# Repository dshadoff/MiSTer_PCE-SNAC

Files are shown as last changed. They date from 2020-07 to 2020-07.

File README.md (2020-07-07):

# MiSTer_PCE-SNAC converter board

This is a board designed to work with the MiSTer FPGA system, and is originally based on
the SNAC designs from blue212 at https://github.com/blue212/SNAC

The PC Engine controller system has higher-speed requirements than most other systems, and
as a result, the regular open-collector SNAC boards don't really work for most situations
(ie. auto-fire, 6-button controller, turbotap, PCE mouse, Memory Base 128, etc.).  This is
because the rise time on the pulses is not fast enough among other things.  This board
was designed to address these issues.

While designing it, I also felt that I wanted as small a board as possible, so I decided
to integrate the regular "surfboard" SNAC and the adapter, integrating them into a single
device.  I also shrunk all the components as much as possible, and chose easily-obtainable
parts so that I could get them assembled by JLCPCB's SMT assembly service at a very good
price.  (However they don't mount connectors.)

I designed the board using the free version of EAGLE (2-layer, less than 100mm on both
X- and Y-axes).  The gerbers are included in this repository, including the files required
by JLCPCB's SMT assembly forms, in case you want to get your own set made.

The board measures 37mm x 22mm (plus USB plug).  Here is a picture:

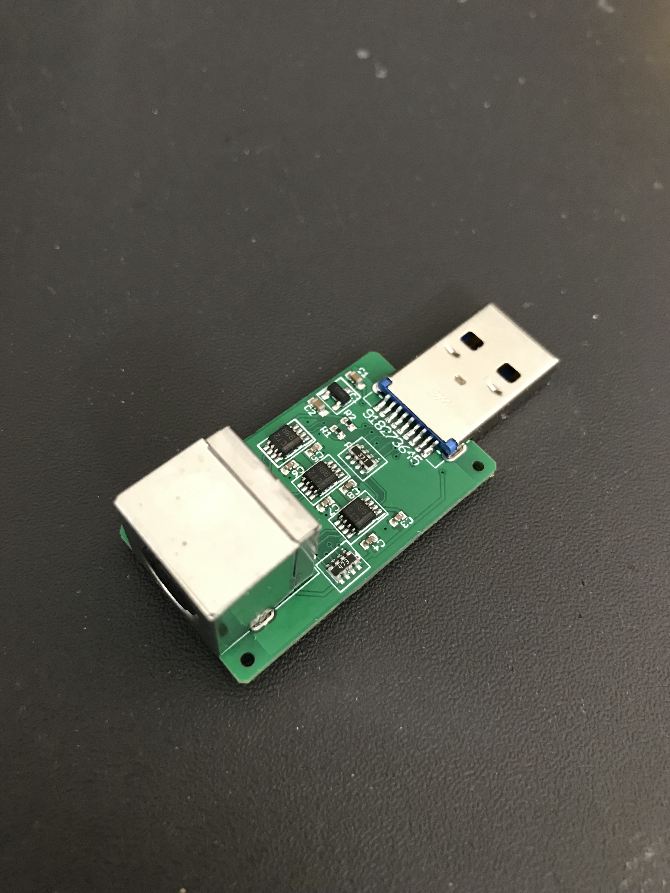
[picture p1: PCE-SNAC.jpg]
PC Board is 37mm x 22mm


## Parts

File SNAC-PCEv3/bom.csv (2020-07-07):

Qty | Designator | Footprint | Comment | LCSC Part # (optional) | Description (optional)
6 | C3, C4, C5, C6, C7, C8 | C0402 | 100nF ±10% 16V X7R 0402 | C1525 | Samsung CL05B104KO5NNNC
2 | C1, C2 | C0603 | 1uF ±10% 50V X5R 0603 | C15849 | Samsung CL10A105KB8NNNC
2 | R1, R2 | R0402 | 3.9K ±1% 1/16W 0402 | C51721 | UNI-ROYAL 0402WGF3901TCE
1 | K2 | through-hole | do not mount |  | USB 3.0 male plug - DO NOT MOUNT
1 | IC1 | SOT-23-3 | MCP1700T-3302E/TT | C39051 | MCP1700T-3302E_TT LDO voltage regulator 250mA Isupply 1uA
1 | J1 | through-hole | do not mount |  | mini-DIN 8-pin socket - DO NOT MOUNT
3 | IC2, IC3, IC4 | SM8 | SN74LVC2T45DCTR | C22672 | Translation - Voltage Levels DUAL-BIT DUAL SUPPLY TRANSCEIVER
1 | RN2 | 0603_x4 | 330 ±5% x4 1/16W network | C12018 | UNI-ROYAL 4D03WGJ0331T5E
1 | RN1 | 0603_x4 | 47K ±5% x4 1/16W network | C12027 | UNI-ROYAL 4D03WGJ0473T5E

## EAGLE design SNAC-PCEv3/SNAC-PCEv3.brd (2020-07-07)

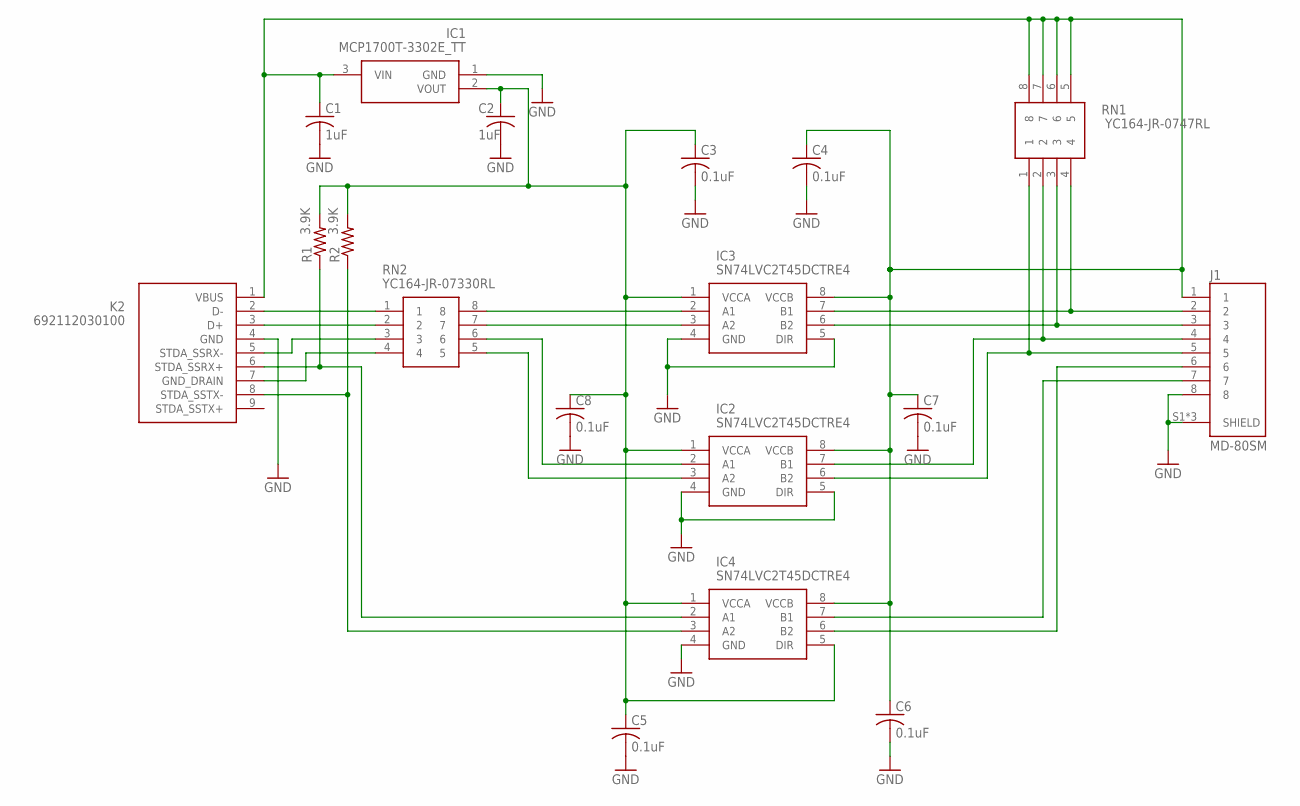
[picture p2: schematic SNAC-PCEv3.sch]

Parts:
C1, C2: 1uF; C0603
C3, C4, C5, C6, C7, C8: 0.1uF; C0402
IC1: MCP1700T-3302E_TT; SOT95P237X112-3N
IC2, IC3, IC4: SN74LVC2T45DCTRE4; SOP65P400X130-8N
J1: MD-80SM; CUI_MD-80SM
K2: 692112030100; MPN TXS0108EPWR
R1, R2: 3.9K; R0402
RN1: YC164-JR-0747RL; YC164JR07220RL
RN2: YC164-JR-07330RL; YC164JR07220RL

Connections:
3V3: C2.1, C3.1, C5.1, C8.1, IC1.2 (VOUT), IC2.1 (VCCA), IC3.1 (VCCA), IC4.1 (VCCA), IC4.5 (DIR), R1.2, R2.2
5V: C1.1, C4.1, C6.1, C7.1, IC1.3 (VIN), IC2.8 (VCCB), IC3.8 (VCCB), IC4.8 (VCCB), J1.1, K2.1 (VBUS), RN1.5, RN1.6, RN1.7, RN1.8
GND: C1.2, C2.2, C3.2, C4.2, C5.2, C6.2, C7.2, C8.2, IC1.1 (GND), IC2.4 (GND), IC2.5 (DIR), IC3.4 (GND), IC3.5 (DIR), IC4.4 (GND), J1.8, J1.S1 (SHIELD), J1.S2 (SHIELD), J1.S3 (SHIELD), K2.4 (GND)
unnamed: K2.2 (D-), RN2.1
unnamed: IC3.7 (B1), J1.2, RN1.4
unnamed: IC3.3 (A2), RN2.7
unnamed: IC2.7 (B1), J1.4, RN1.2
unnamed: IC3.2 (A1), RN2.8
unnamed: K2.3 (D+), RN2.2
unnamed: K2.5 (STDA_SSRX-), RN2.3
unnamed: IC4.7 (B1), J1.7
unnamed: IC3.6 (B2), J1.3, RN1.3
unnamed: IC2.6 (B2), J1.5, RN1.1
unnamed: IC4.6 (B2), J1.6
unnamed: IC2.2 (A1), RN2.6
unnamed: K2.7 (GND_DRAIN), RN2.4
unnamed: IC2.3 (A2), RN2.5
RX+: IC4.2 (A1), K2.6 (STDA_SSRX+), R1.1
TX-: IC4.3 (A2), K2.8 (STDA_SSTX-), R2.1

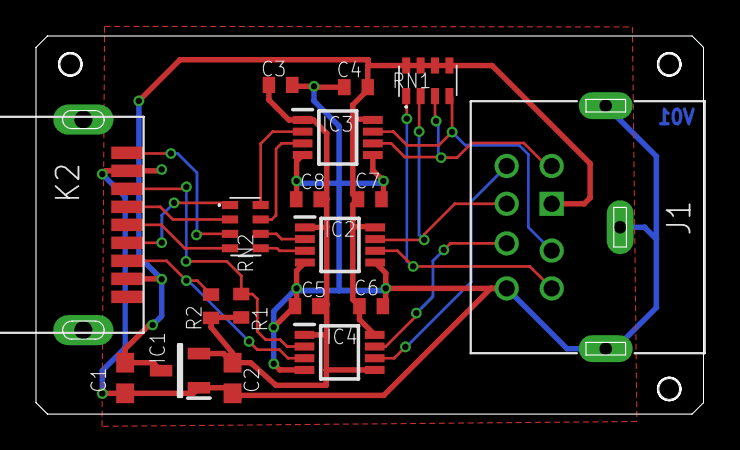
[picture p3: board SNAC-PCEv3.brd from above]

Board: 2 copper layers, 37.1 x 21.0 mm, 18 parts (0 on the bottom side), 19 nets.

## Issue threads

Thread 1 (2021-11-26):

Inputs problem

sk8er000, 2021-11-26:
I've just assembled a PCB and the dpad is not recognized, the strange part is that when another button is pressed (without pressing any direction) the other button is recognized together with a direction (one for each button).
A regular USB snac is working with the same mister setup

dshadoff, 2021-11-26:
That sounds like a short or an incomplete circuit... from your description, it would be related to the "Select" line from the PC Engine.

Suspects include the USB connector, pullup resistors R1 or R2, pins 2&3 into IC4, IC4 itself (including power), pins 6&7 out of IC4, and the mini-DIN8.

Check continuity along these paths, and ensure that they aren't shorted to any of: Gnd, 3V3 supply, or 5V supply.

The reverse path sounds OK.

dshadoff, 2021-11-26:
Also check that:
- pins 1 & 5 of IC4 are getting 3v3 properly
- pin 4 is grounded, and
- pin 8 is getting 5V

sk8er000, 2021-11-26:
Thank you for the answer I'll try to triple check everything again. Could it be related to some faulty component or other?
I've checked all the PCB components but it seems everything ok.
With regular SNAC (tried both USB and HDMI version) the PCE adapter is working fine, so it shouldn't be a I/O board issue..
I can try to assemble a second PCB to see if there is a similar behaviour. On the actual PCB I can't notice anything suspicious..it seems like the signals on the same remains tied together and can't be properly recognized.
Here's a couple of pics of my PCB:
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

dshadoff, 2021-11-26:
Well, appearance looks OK, but you really need to do some continuity testing... looking at the board doesn't always show you all the possible problems.

The SELECT line is driven from the SNAC port, and passes via the USB connector into IC4, which does a level-shift, and then sends it out the PCE DIN socket.  SELECT tells the PCE controller whether to send back D-pad information, or the buttons.  Somehow it seems to be jammed on your board.  This could be due to an open circuit, or a short - so that the SELECT line's actual level never makes it to the controller.

One class of issue would be "open circuit", where a solder joint isn't correct.  This doesn't *appear* to be the case, but you can only be certain with continuity testing between the input pin (before the solder connection to the board) and the output pin (after the solder connection from the board).  This could also be the case if IC4 had a problem.  You might want to double-check pins 6 and 7 on IC4; they're hard to see clearly, but the solder joint might not be perfect there.

The second class of issues would be either "short to ground" or "short to power supply".  This could be a case where two adjacent pins are soldered together.  This doesn't *appear" to be the case, from your pictures but occasionally this can happen underneath a chip or a resistor.  This problem could also manifest if the pullup resistor was the wrong value (too low).

So, it's a case of checking the everything which should be connected is actually connected, and that everything which should be kept disconnected remains disconnected.  If you have an oscilloscope, you should be able to check the waveforms at the entrance to IC4 and the exit from IC4.  The "CLR" signal should toggle once every 1/60th of a second while playing a game, and the "SELECT" signal should toggle 5 times in a brief period when the CLR signal transitions.

sk8er000, 2021-11-27:
While I was trying to debug the problem I noticed that signals weren't as described. Fortunately the issue was very obvious.. probably I was distracted while assembling the PCB and soldered R1 and R2 wrong (90° rotated). Sorry to bothered you

Closed 2021-11-27.

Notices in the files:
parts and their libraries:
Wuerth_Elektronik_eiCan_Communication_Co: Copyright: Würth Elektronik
